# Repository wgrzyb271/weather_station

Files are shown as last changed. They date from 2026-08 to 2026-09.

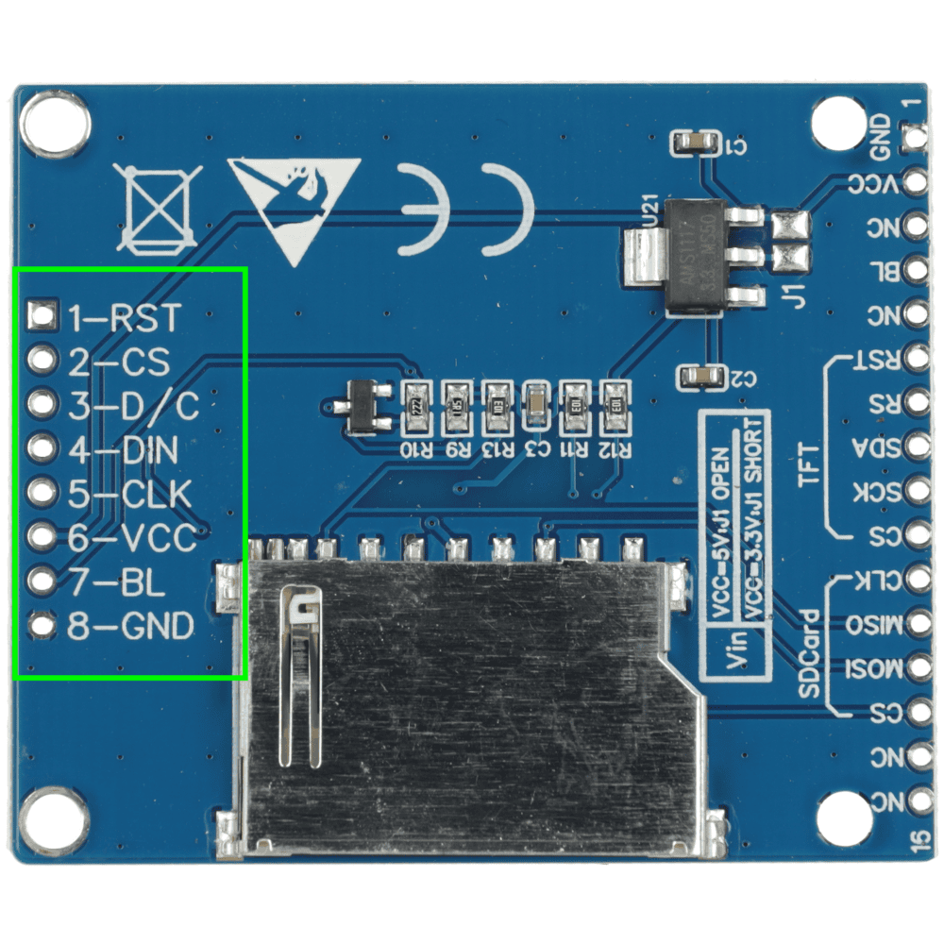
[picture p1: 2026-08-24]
hardware/datasheets/tft.png

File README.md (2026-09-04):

# 🌡️ ESP32-C6 Indoor Weather Station

An open-source indoor environmental monitoring system built on a custom **ESP32-C6-WROOM-1** dev board. It measures temperature, relative humidity, barometric pressure, and air quality (IAQ) using the **Bosch BME680**, displaying real-time metrics on a color TFT screen with dynamic, flicker-free backlight dimming.

Designed using **KiCad** for hardware development and programmed via **PlatformIO**.

---

## ✨ Features

* **Environmental Sensing:** High-accuracy indoor temperature, humidity, barometric pressure, and Gas/IAQ metrics via Bosch BME680.
* **Dynamic Backlight Control:** Ambient light-sensing using a photoresistor (LDR) voltage divider coupled with high-frequency PWM.
* **IEEE 1789 Compliant Dimming:** Backlight PWM frequency tuned to prevent visible flicker and health risks associated with LED dimming, as outlined in the IEEE 1789-2015 standard.
* **Custom Hardware:** Tailored PCB designed from scratch around the ESP32-C6 module.
* **TFT Display UI:** Real-time data visualization on a vibrant color LCD screen.
* **3D-Printed Enclosure:** Protective cover for the circuit designed in **FreeCAD**, sized to fit the custom PCB and TFT cutout.

---

## 🛠️ Hardware Overview

| Component | Details |
|---|---|
| **Microcontroller** | ESP32-C6-WROOM-1 (RISC-V 32-bit single-core, Wi-Fi 6, Bluetooth 5, 802.15.4 / Thread / Zigbee) |
| **Environmental Sensor** | Bosch BME680 (I2C) |
| **Display** | ST7735 TFT Display (SPI) |
| **Light Sensing** | Photoresistor (LDR) in a voltage divider network connected to an ESP32-C6 ADC pin |
| **Backlight Control** | TFT backlight pin driven directly via the ESP32-C6 **LEDC (LED Control)** peripheral to generate high-frequency PWM for IEEE 1789-compliant dimming |

<p align="center">
  Schematic - Power Section
  Schematic - MCU Section
</p>

---

## 💻 Tech Stack & Libraries

* **EDA / Hardware:** [KiCad](https://www.kicad.org/) (Schematics & PCB Layout)
* **3D CAD / Enclosure:** [FreeCAD](https://www.freecad.org/) (Circuit cover / enclosure design)
* **Firmware Framework:** [PlatformIO](https://platformio.org/) on Arduino Core
* **Core Libraries:**
  * `Adafruit_ST7735` & `Adafruit_GFX` – Display driver and graphics library
  * `Adafruit_BME680` & `Adafruit_Sensor` – Environmental sensor driver
  * `Wire.h` & `SPI.h` – Hardware bus communication

---

## 📋 Project Management

This project is managed using [Plane](https://app.plane.so) — an open-source Jira/Confluence alternative — for issue tracking, sprints, and documentation. Feature requests, bugs, and task boards live there rather than solely in GitHub Issues.

---

## 🗺️ Roadmap / Planned Features

* **Zephyr RTOS Port:** Migrate firmware from Arduino Core to Zephyr RTOS for improved power management, native threading, and better long-term driver support on the ESP32-C6.
* **MQTT Broker Integration:** Publish sensor readings (temperature, humidity, pressure, IAQ) to an MQTT broker, with support for **Home Assistant** MQTT auto-discovery.
* **OTA Firmware Updates:** Over-the-air update support to avoid re-flashing over USB for field-deployed units.
* **Web Configuration Portal:** Captive-portal Wi-Fi provisioning and settings UI served directly from the ESP32-C6.
* **Historical Data Logging:** Local logging (SD card or flash) with optional export/graphing.

> Have a feature request? Open an [issue](../../issues) or start a [discussion](../../discussions).

---

## 🚀 Getting Started

### 1. Hardware Design

Schematics, PCB layout files, and BOM (Bill of Materials) can be found in the [`/hardware`](./hardware) directory. Open them with **KiCad 10.0+**.

### 2. Firmware Compilation

1. Install [Visual Studio Code](https://code.visualstudio.com/) and the [PlatformIO extension](https://platformio.org/platformio-ide).
2. Clone this repository:
   ```bash
   git clone https://github.com/your-username/your-repo-name.git
   cd your-repo-name
   ```
3. Open the project folder in VS Code — PlatformIO should detect the `platformio.ini` automatically and install the required libraries and toolchain.
4. Connect the ESP32-C6-WROOM-1 board via USB.
5. Build and upload:
   ```bash
   pio run --target upload
   ```
6. Monitor serial output:
   ```bash
   pio device monitor
   ```

---

## 📁 Repository Structure

```
.
├── hardware/        # KiCad schematics, PCB layout, and BOM
├── enclosure/        # FreeCAD source files and exported STL/STEP for the cover
├── src/              # Firmware source code
├── include/          # Header files
├── lib/               # Project-specific libraries
├── platformio.ini    # PlatformIO project configuration
└── README.md
```

---

## 🤝 Contributing

Contributions, issues, and feature requests are welcome. Feel free to check the [issues page](../../issues) or submit a pull request.

---

## 📄 License

This project is licensed under the terms of the license included in this repository — see [`LICENSE`](./LICENSE) for details.

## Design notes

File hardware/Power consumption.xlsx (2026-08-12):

Module | Peak current [mA] | Avg current [mA]
ESP32-C6-WROOM-1-N8 WiFi in Active Mode | 382
ESP32-C6-WROOM-1-N8 Bluetooth LE in Active Mode | 309
BME680 | 18 | 17
TFT display (ST7735S) | 50
Voltage divider (LDR + resistor) | 1
SUM | 760 | 17
LDOs | Chosen LDO | Explanation
SGM2212-3.3
AMS1117-3.3
MCP1700
DC Converters | Chosen converter | Explanation

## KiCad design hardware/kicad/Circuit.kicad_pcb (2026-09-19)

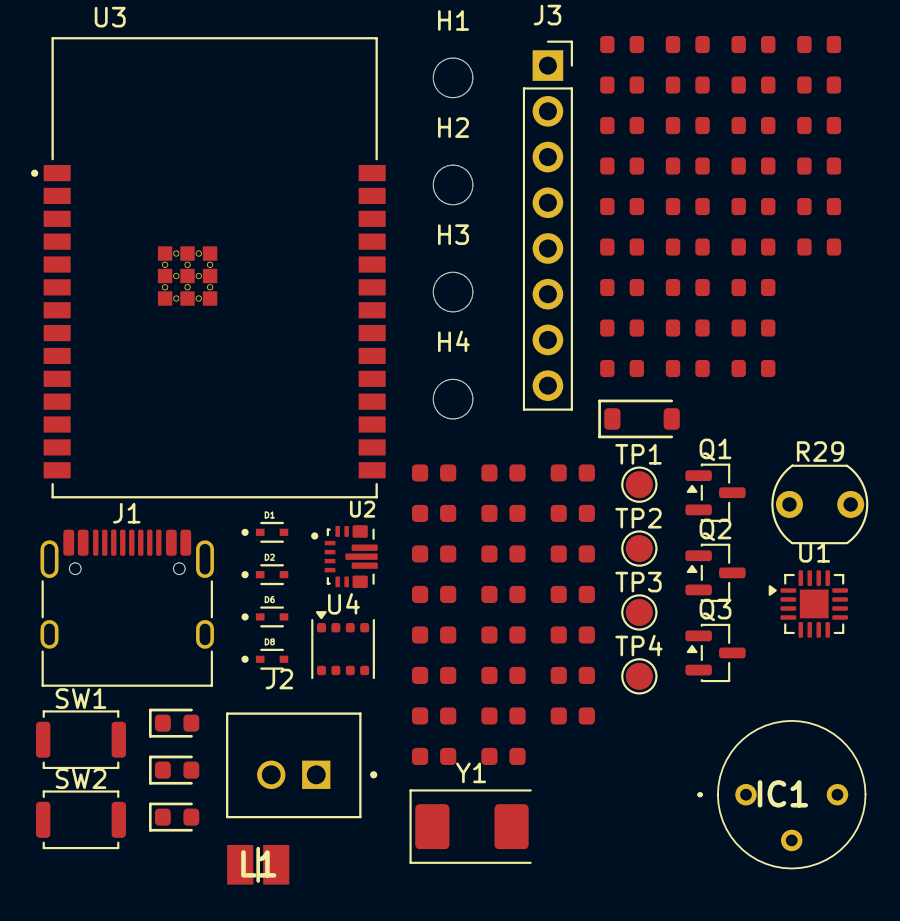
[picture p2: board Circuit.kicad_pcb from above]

Board: 2 copper layers, 88 parts (0 on the bottom side), 53 nets, no tracks yet.

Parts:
C1, C10, C15, C19: 1uF; C_0603
C2, C3, C5: 4.7uF; C_0603
C4, C6: 2.2uF; C_0603
C7, C8, C9, C16: 10uF; C_0603
C11, C13, C14, C17, C18, C20, C23: 100nF; C_0603
C12: 22uF; C_0603
C21, C22: 12pF; C_0603
D1, D2, D6, D8: LESD5D5.0CT1G; TVS_LESD5D5.0CT1G
D3: Green; D_0603
D4: Red; D_0603
D5: BZT52C6V2; D_SOD-123
D7: Blue; D_0603
H1, H2, H3, H4: MountingHole; MountingHole_2.2mm_M2
IC1: AS312
J1: USB_C_Receptacle_USB2.0_14P; USB_C_Receptacle_HRO_TYPE-C-31-M-12
J2: B2B-XH-A__LF__SN_; JST_B2B-XH-A__LF__SN_
J3: Conn_01x08_Socket; PinSocket_1x08_P2.54mm_Vertical
L1: 1.5uH 4A; INDC2520X100N
Q1, Q2: AO3401A; SOT-23
Q3: AO3400A; SOT-23
R1: 75K; R_0603
R2: 1.6K; R_0603
R3: 1.78K; R_0603
R4, R5: 5k1; R_0603
R6, R14: 470K; R_0603
R7, R8: 1.5K; R_0603
R9, R10, R11, R12, R16, R21, R22, R25, R26: 100K; R_0603
R13, R18, R19, R20, R24: 10K; R_0603
R15: 150K; R_0603
R17: 1K; R_0603
R23: 220; R_0603
R27: 330; R_0603
R28, R31, R32: 4.7K; R_0603
R29: R_Photo; R_LDR_5.1x4.3mm_P3.4mm_Vertical
R30: 30K; R_0603
R33: 10M; R_0603
SW1, SW2: SW_Push; SW_Push_SPST_NO_Alps_SKRK
TH1: 10K; R_0603
TP1: TP_SYS; TestPoint_Pad_D1.5mm
TP2: TP_VBUS; TestPoint_Pad_D1.5mm
TP3, TP4: TP_+3V3; TestPoint_Pad_D1.5mm
U1: BQ24075RGT; VQFN-16-1EP_3x3mm_P0.5mm_EP1.6x1.6mm
U2: TPS63070RNMR; VREG_TPS63070RNMR
U3: ESP32-C6-WROOM-1-N8; XCVR_ESP32-C6-WROOM-1-N8
U4: BME680; Bosch_LGA-8_3x3mm_P0.8mm_ClockwisePinNumbering
Y1: 32.768 kHz; Crystal_SMD_0603-2Pin_6.0x3.5mm

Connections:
+3.3V: C8.1, C12.1, C16.2, C17.2, C18.2, C19.1, C20.1, C23.1, D8.2, IC1.1 (VDD), J3.6, R14.1, R16.1, R17.1, R20.1, R27.1, R28.2, R29.1, R31.1, R32.1, TP3.1 (1_1), U2.7_8 (VOUT), U3.2 (3V3), U4.2 (CSB), U4.6 (VDDIO), U4.8 (VDD)
+5V: C1.1, C2.2, C6.2, D5.1, D6.2, Q1.2 (S), R25.1, TP2.1 (1_1), U1.13 (IN)
BAT: C5.1, J2.1, Q2.2 (S), R11.1, U1.2 (BAT), U1.3 (BAT)
BAT_ADC: C10.2, C11.2, R9.2, R10.1, U3.26 (IO3)
BAT_CTRL: R12.1, U3.12 (IO11)
BL: J3.7, Q3.3 (D), R28.1
CHG_EN1: R21.1, U1.6 (EN1), U3.27 (IO2)
CHG_EN2: R22.1, U1.5 (EN2), U3.24 (RXD0/GPIO17)
D+: D2.2, J1.A6 (D+), J1.B6 (D+), U3.14 (IO13)
D-: D1.2, J1.A7 (D-), J1.B7 (D-), U3.13 (IO12)
DPM_OUT: C3.1, C7.1, C9.1, D3.2, D4.2, R13.1, TP1.1 (1_1), U1.10 (OUT), U1.11 (OUT), U2.12_13 (VIN)
FB: R14.2, R15.1, U2.5 (FB)
GND: C1.2, C2.1, C3.2, C4.1, C5.2, C6.1, C7.2, C8.2, C9.2, C10.1, C11.1, C12.2, C13.2, C14.2, C15.2, C16.1, C17.1, C18.1, C19.2, C20.2, C21.1, C22.1, C23.2, D1.1, D2.1, D6.1, D8.1, IC1.3 (VSS), J1.A1 (GND), J1.A12 (GND), J1.B1 (GND), J1.B12 (GND), J1.SH (SHIELD), J2.2, J3.8, Q3.2 (S), R1.1, R4.2, R5.2, R6.2, R10.2, R15.2, R19.2, R21.2, R22.2, R24.1, R26.2, R30.1, SW1.1, SW2.2, TH1.2, U1.8 (VSS), U1.17 (VSS), U2.4 (GND), U2.6 (FB2), U2.10 (PGND), U2.15 (VSEL), U3.1 (GND), U3.28 (GND), U3.29_1 (GND), U3.29_2 (GND), U3.29_3 (GND), U3.29_4 (GND), U3.29_5 (GND), U3.29_6 (GND), U3.29_7 (GND), U3.29_8 (GND), U3.29_9 (GND), U4.1 (GND), U4.5 (SDO), U4.7 (GND)
LDR: R29.2, R30.2, U3.4 (IO4)
unnamed: D3.1, R7.1
unnamed: D4.1, R8.1
unnamed: D7.2, R27.2
unnamed: IC1.2 (REL), R18.2, R19.1
unnamed: J1.A5 (CC1), R5.1
unnamed: J1.B5 (CC2), R4.1
unnamed: J1.A4 (VBUS), J1.A9 (VBUS), J1.B4 (VBUS), J1.B9 (VBUS), Q1.3 (D)
unnamed: C4.2, D5.2, Q1.1 (G), R6.1
unnamed: Q2.3 (D), R9.1
unnamed: Q2.1 (G), R11.2, R12.2
unnamed: Q3.1 (G), R23.2, R24.2
unnamed: R2.2, U1.12 (ILIM)
unnamed: R3.2, U1.16 (ISET)
unnamed: R2.1, R3.1, U1.4 (~CE), U1.15 (SYSOFF)
unnamed: R1.2, U1.14 (TMR)
unnamed: TH1.1, U1.1 (TS)
unnamed: R13.2, U2.1 (PS/SYNC), U2.14 (EN)
unnamed: L1.2, U2.11 (L1)
unnamed: L1.1, U2.9 (L2)
unnamed: C13.1, U2.3 (VAUX)
unnamed: C14.1, C15.1, R20.2, SW1.2, U3.3 (EN)
unnamed: R17.2, U3.10 (IO8)
unnamed: SW2.1, U3.15 (IO9)
unnamed: D7.1, U3.16 (IO18)
PG: R16.2, U2.2 (PG)
PIR: R18.1, U3.17 (IO19)
PWM: R23.1, U3.23 (IO15)
S_SCL: R32.2, U3.7 (IO7), U4.4 (SCK)
S_SDA: R31.2, U3.6 (IO6), U4.3 (SDI)
TFT_CLK: J3.5, U3.18 (IO20)
TFT_CS: J3.2, U3.11 (IO10)
TFT_DIN: J3.4, U3.19 (IO21)
TFT_D/C: J3.3, U3.20 (IO22)
TFT_RST: J3.1, U3.21 (IO23)
VBUS_SENSE: R25.2, R26.1, TP4.1 (1_1), U3.5 (IO5)
XTAL_N: C21.2, R33.2, U3.9 (IO1), Y1.1
XTAL_P: C22.2, R33.1, U3.8 (IO0), Y1.2
~CHG: R8.2, U1.9 (~CHG)
~PGOOD: R7.2, U1.7 (~PGOOD)

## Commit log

2026-08-12 hardware: power section - first steps
    [Circuit.kicad_pcb, Circuit.kicad_sch, Power consumption.xlsx]
2026-08-24 hardware: power section & components
    [Circuit.kicad_sch, mcu_section.kicad_sch]
2026-08-26 hardware: MCU components
    [Circuit.kicad_sch, mcu_section.kicad_sch]
2026-08-26 hardware: movement sensor
    [Circuit.kicad_sch, mcu_section.kicad_sch]
2026-09-04 hardware: battery voltage reading and caps
    [Circuit.kicad_pcb, Circuit.kicad_sch, mcu_section.kicad_sch]
2026-09-10 hardware: modfied wiring
    [Circuit.kicad_sch, mcu_section.kicad_sch]
2026-09-12 hardware: ldr voltage divider
    [Circuit.kicad_pcb, mcu_section.kicad_sch]
2026-09-17 fix: incorrect values and missing wirings
    [Circuit.kicad_sch, mcu_section.kicad_sch]
2026-09-19 feat: manufacturer part numbers
    [Circuit.kicad_pcb, Circuit.kicad_sch, mcu_section.kicad_sch]
